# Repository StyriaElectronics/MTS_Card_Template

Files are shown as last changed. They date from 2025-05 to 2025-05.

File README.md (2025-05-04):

# 🧩 MTS (Modular Test System) – Card Template

The **Modular Test System – Card Template** provides a base design for plug-in boards that slide into a standard **3U 42TE rack**.  
These boards interface with a central **backplane**, enabling power distribution and inter-module communication.  
Perfect for rapid development of sensor, signal, communication, or analog cards — with a clean KiCad layout ready to extend.

---







---

## 📦 Project Contents

- `.kicad_pro` – Project file
- `.kicad_sch` – Schematic
- `.kicad_pcb` – PCB layout
- `*-backups/*.zip` – Gerber backup ZIPs for production
- `.gitignore`, `LICENSE`, `README.md`

---

## 🛠 Requirements

- [KiCad 8.x](https://www.kicad.org/)
- Optional: [Gerber Viewer](https://gerbv.geda-project.org/) or JLCPCB/PCBWay web viewer

---

## 🚀 Open the Project

```bash
# Clone the repository
git clone https://github.com/StyriaElectronics/MTS_Card_Template.git

# Open the project in KiCad
open MTS_Card_Template.kicad_pro
```

---

## 📘 MTS System – Technical Specification

- 📄 [🇩🇪 Deutsch – MTS_Specification.md](specs/MTS_Specification.md)  
- 📄 [🇬🇧 English – MTS_Specification_EN.md](specs/MTS_Specification_EN.md)

---

## 🧪 Export Gerber Files

To export new Gerber files from KiCad:

1. Open the `.kicad_pcb` file in KiCad
2. Go to File > Plot > Gerber
3. Optionally, ZIP the result:
   ```bash
   zip -r Gerber_Export.zip <folder>
   ```

---

## 📃 License

This project is licensed under the  
**[Creative Commons Attribution 4.0 International (CC BY 4.0)](https://creativecommons.org/licenses/by/4.0/)** license.

> You may use, modify, and share the project – **as long as you give proper credit to the author**.

Author: **Styria Electronics András Nagy**  
Website: [styria-electronics](https://styria-electronics.at)

---
## ⚠️ Disclaimer
This project is provided "as is" without warranty of any kind, either expressed or implied.  
In no event shall the author(s) be liable for any claim, damages, or other liability arising from, out of, or in connection with the use or other dealings in this project.

## 🤝 Contributing

Pull requests, issues, and forks are always welcome!

---

## ⭐️ If You Like It...

... give this project a star ⭐️ on GitHub!

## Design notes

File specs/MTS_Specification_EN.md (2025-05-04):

# 📘 MTS – Modular Test System: Specification

**Version:** 1.1
**Author:** András Nagy
**License:** CC BY-NC 4.0
**Date:** 04.05.2025

---

## 📐 1. Mechanical Dimensions

### 1.1 PCB Size

* Total width: 159.95 mm
* Total height: 100.00 mm
* PCB thickness: 1.6 mm

### 1.2 Mounting Holes

* 2 mounting holes Ø 3.2 mm
* Positions:

  * Bottom left: 6 mm from left / 6 mm from bottom
  * Top right: 6 mm from right / 5.5 mm from top

### 1.3 Keepout Zones

* 5 mm at top and bottom edges (for guide rails)

---

## 🔌 2. Connectors

* **Type:** DIN 41612, Type C (ZB), 2x16 Pins
* **Footprint:** `DIN41612_02x16_ZB`
* **Mounting:** vertical at the right PCB edge
* **Connector:** Pin header on module, socket on CPU board

---

## 📍 3. Pin Assignment

| Pin | Signal | Description |
| --- | --- | --- |
| a1 | Trigger | Trigger input |
| b1 | CAN\_H | CAN Bus High |
| b2 | CAN\_L | CAN Bus Low |
| b3 | I2C\_BUS\_SDA | I²C Data line |
| b4 | I2C\_BUS\_CLK | I²C Clock line |
| a11–a12 | +12 V | Supply +12 V (1 A) |
| b11–b12 | –12 V | Supply –12 V (0.2 A) |
| a13–a14 | +3.3 V Ext | Supply 3.3 V (0.5 A) |
| a15–a16 | +5 V Ext | Supply 5 V (1 A) |
| b13–b16 | GND | Ground |

> Unassigned pins may be used for specific projects.

---

## ⚡ 4. Power Supply

| Voltage | Range | Max. Current |
| --- | --- | --- |
| +12 V | 11.5–12.5 V | 1 A |
| –12 V | –11.5– –12.5 V | 0.2 A |
| +3.3 V  | 3.2–3.4 V | 0.5 A |
| +5 V | 4.9–5.2 V | 1 A |

> ⚠️ No back-feeding from modules!

---

## 🖥️ 5. Communication Buses

### 5.1 I²C

* Standard Mode: 100 kHz
* Pull-up resistors on CPU board

### 5.2 CAN

* ISO 11898 compatible
* Galvanic isolation (optional)
* Termination: 120 Ω on CPU board

### 5.3 EtherCAT

* High-speed real-time communication
* EtherCAT according to IEC 61158 standard
* RJ45 connector on CPU board
* Supports data rates up to 100 Mbit/s
* Dedicated EtherCAT modules for fast data acquisition and control

---

## 🧩 Module Categories

| Type | Function |
| --- | --- |
| CPU board | Central control unit (e.g., Raspberry Pi CM4) |
| IO cards | Relays, Optocouplers, PWM, Digital Inputs |
| DAQ cards | ADC cards, DAC cards, Sensor interfaces |
| Interface cards | EtherCAT Slave, CAN bus, RS485/Modbus, UART |
| Power cards | DC/DC converters, Load drivers, Fuse and monitoring cards |
| Wireless cards  | Wi-Fi/Bluetooth, LoRa/LPWAN |
| Special cards | Calibration, Multiplexer, Signal processing cards |

---

## 📄 7. License

This project is licensed under
[**Creative Commons Attribution-NonCommercial 4.0 International (CC BY-NC 4.0)**](https://creativecommons.org/licenses/by-nc/4.0/)

**Commercial use requires a separate license agreement.**

---

**© 2025 Styria Electronics**

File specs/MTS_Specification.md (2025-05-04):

# 📘 MTS – Modular Test System: Spezifikation

**Version:** 1.1
**Autor:** András Nagy
**Lizenz:** CC BY-NC 4.0
**Stand:** 04.05.2025

---

## 📐 1. Mechanische Abmessungen

### 1.1 Platinengröße

* Gesamtbreite: 159,95 mm
* Gesamthöhe: 100,00 mm
* PCB-Dicke: 1,6 mm

### 1.2 Bohrungen

* 2 Montagelöcher Ø 3,2 mm
* Position:

  * Links unten: 6 mm von links / 6 mm von unten
  * Rechts oben: 6 mm von rechts / 5,5 mm von oben

### 1.3 Keepout-Zonen

* 5 mm an Ober- und Unterkante (für Führungsschienen)

---

## 🔌 2. Steckverbinder

* **Typ:** DIN 41612, Type C (ZB), 2x16 Pins
* **Footprint:** `DIN41612_02x16_ZB`
* **Montageart:** senkrecht an rechter PCB-Kante
* **Leiste:** Stiftleiste auf Modul, Buchse auf CPU-Board

---

## 📍 3. Pinbelegung

| Pin | Signal | Beschreibung |
| --- | --- | --- |
| a1 | Trigger | Trigger-Eingang |
| b1 | CAN\_H | CAN Bus High |
| b2 | CAN\_L | CAN Bus Low |
| b3 | I2C\_BUS\_SDA | I²C Datenleitung |
| b4 | I2C\_BUS\_CLK | I²C Taktleitung |
| a11–a12 | +12 V | Versorgung +12 V (1 A) |
| b11–b12 | –12 V | Versorgung –12 V (0.2 A) |
| a13–a14 | +3.3 V Ext | Versorgung 3.3 V (0.5 A) |
| a15–a16 | +5 V Ext | Versorgung 5 V (1 A) |
| b13–b16 | GND | Masse |

> Nicht belegte Pins können projektspezifisch verwendet werden.

---

## ⚡ 4. Spannungsversorgung

| Spannung | Bereich | Max. Strom |
| --- | --- | --- |
| +12 V | 11.5–12.5 V | 1 A |
| –12 V | –11.5– –12.5 V | 0.2 A |
| +3.3 V | 3.2–3.4 V | 0.5 A |
| +5 V | 4.9–5.2 V | 1 A |

> ⚠️ Keine Rückspeisung vom Modul!

---

## 🖥️ 5. Kommunikationsbusse

### 5.1 I²C

* Standard Mode: 100 kHz
* Pullups auf CPU-Board

### 5.2 CAN

* ISO 11898-kompatibel
* galvanisch entkoppelt (optional)
* Terminierung: 120 Ω auf CPU-Board

### 5.3 EtherCAT

* Hochgeschwindigkeits-Echtzeit-Kommunikation
* EtherCAT nach IEC 61158 Standard
* RJ45-Anschluss auf CPU-Board
* Unterstützt Datenraten bis zu 100 Mbit/s
* Dedizierte EtherCAT-Module für schnelle Datenerfassung und Steuerung

---

## 🧩 Modul-Kategorien

| Typ | Funktion |
| --- | --- |
| CPU-Board | zentrale Steuerung (z. B. Raspberry Pi CM4) |
| IO-Karten | Relais, Optokoppler, PWM, Digitale Eingänge |
| DAQ-Karten | ADC-Karten, DAC-Karten, Sensorinterfaces |
| Interfacekarten  | EtherCAT-Slave, CAN-Bus, RS485/Modbus, UART |
| Leistungs-Karten | DC/DC-Konverter, Lasttreiber, Sicherungs- und Überwachung |
| Wireless-Karten  | Wi-Fi/Bluetooth, LoRa/LPWAN |
| Spezialkarten | Kalibrations-, Multiplexer-, Signalverarbeitungskarten |

---

## 📄 7. Lizenz

Dieses Projekt steht unter der
[**Creative Commons Attribution-NonCommercial 4.0 International (CC BY-NC 4.0)**](https://creativecommons.org/licenses/by-nc/4.0/)

**Kommerzielle Nutzung ist ohne separate Lizenz nicht gestattet.**

---

**© 2025 Styria Electronics**

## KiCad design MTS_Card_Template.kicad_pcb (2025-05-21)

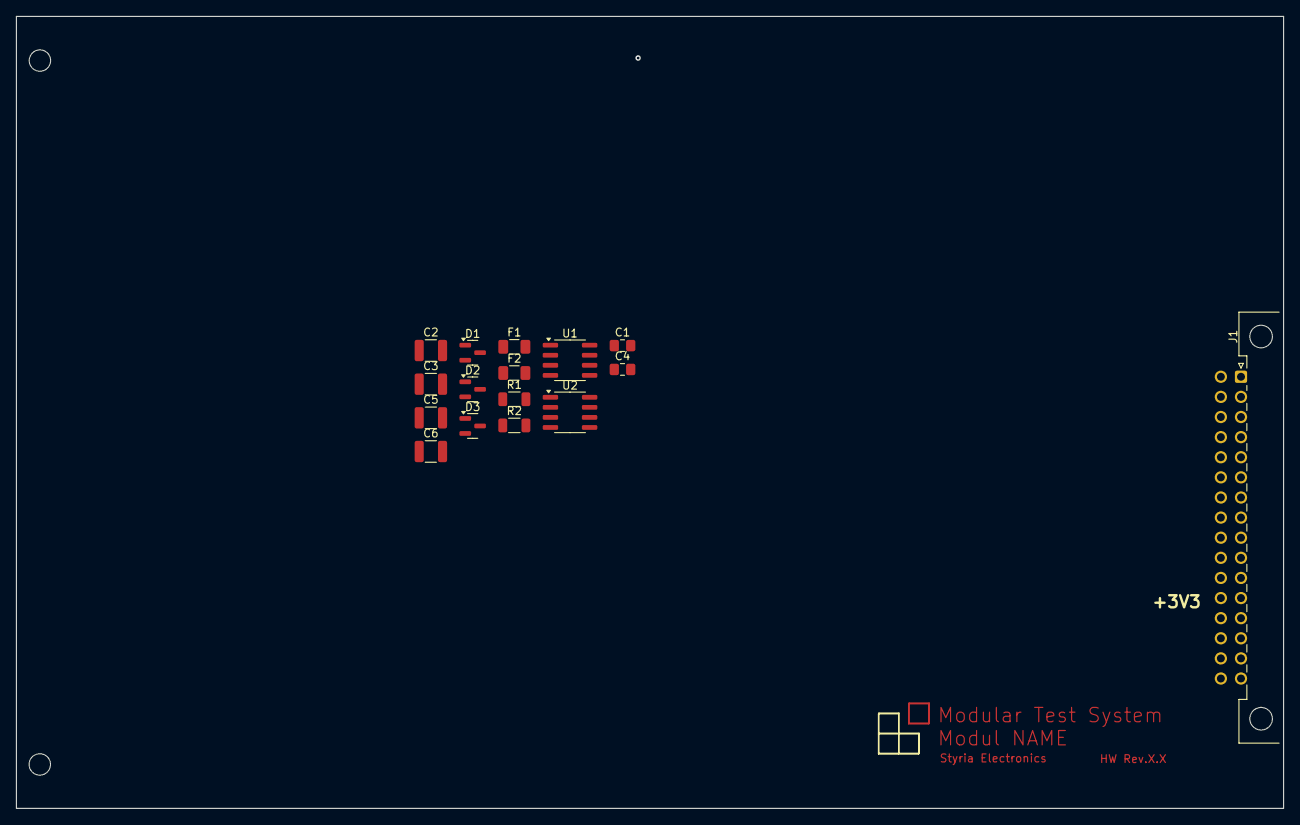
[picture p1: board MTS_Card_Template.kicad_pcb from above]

Board: 6 copper layers, 160.0 x 100.0 mm, 19 parts (1 on the bottom side), 16 nets.

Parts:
C1, C4: 100nF; C_0805_2012Metric_Pad1.18x1.45mm_HandSolder
C2, C3, C5, C6: 47µF; C_1210_3225Metric
D1: PESD3V3L2BT; SOT-23
D2, D3: PESD2CANFD24V-T; SOT-23
F1, F2: Fuse; Fuse_1206_3216Metric
J1: DIN41612_02x16_ZB; DIN41612_B2_2x16_Male_Horizontal_THT
MH1, MH3: MountingHole_2.7mm_M2.5_DIN965
QR Code: LOGO
R1, R2: 0.20Ω; R_1206_3216Metric
U1, U2: INA219AxD; SOIC-8_3.9x4.9mm_P1.27mm

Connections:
+3V3: R1.2, R2.2, U1.5 (VS), U1.7 (IN-), U2.1 (A1), U2.5 (VS), U2.7 (IN-)
+3V3Ext: C1.1, C2.1, C3.1, C4.1, C5.1, C6.1, F1.2, F2.2, J1.a13 (Pin_z13), J1.a14 (Pin_z14)
+5VExt: J1.a15 (Pin_z15), J1.a16 (Pin_z16)
+12V: J1.a11 (Pin_z11), J1.a12 (Pin_z12)
-12V: J1.b11, J1.b12
/Conn/CAN_H: D3.2 (K), J1.b1
/Conn/CAN_L: D3.1 (K), J1.b2
/Conn/I2C_BUS_CLK: D2.1 (K), J1.b4
/Conn/I2C_BUS_SDA: D2.2 (K), J1.b3
/Conn/SYNC_CPU: D1.1 (K), J1.a2 (Pin_z2)
/Conn/Triger: D1.2 (K), J1.a1 (Pin_z1)
GND: C1.2, C2.2, C3.2, C4.2, C5.2, C6.2, D1.3 (A), D2.3 (A), D3.3 (A), J1.b13, J1.b14, J1.b15, J1.b16, U1.1 (A1), U1.2 (A0), U1.6 (GND), U2.2 (A0), U2.6 (GND)
I2C1_SCL: U1.4 (SCL), U2.4 (SCL)
I2C1_SDA: U1.3 (SDA), U2.3 (SDA)
unnamed: F1.1, R1.1, U1.8 (IN+)
unnamed: F2.1, R2.1, U2.8 (IN+)

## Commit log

2025-04-07 Edit Connector
    [MTS_Card_Template.kicad_pcb, MTS_Card_Template.kicad_sch]
2025-05-21 Update Connector
    [Conn.kicad_sch, MTS_Card_Template.kicad_pcb, MTS_Card_Template.kicad_sch]

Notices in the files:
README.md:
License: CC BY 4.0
